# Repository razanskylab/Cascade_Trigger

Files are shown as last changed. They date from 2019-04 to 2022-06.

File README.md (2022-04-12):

# Cascade Trigger

This library was originally written to allow multiwavelength imaging in optoacoustic microscopy. After a position trigger coming from the Quadrature decoder, this library will make a burst mode trigger scheme allowing the acquisition of multiwavelength OA images within a single mechanical overfly scan. We provide a convenient MATLAB interface to define the required number of averages and number of wavelengths.

The code was tested with Teensy 3.6 and Teensy 4.1 and should be compatible with both. To programm the controller you need to download and install [Teensyduino](https://www.pjrc.com/teensy/teensyduino.html).

Depending on how you use the library, you might need to adapt a few ports.

## Literature

*  Urs A. T. Hofmann, Johannes Rebling, Héctor Estrada, Pavel Subochev, Daniel Razansky: Rapid functional optoacoustic micro-angiography in a burst mode, Optics Letters 45 (9) 2020, DOI: [10.1364/OL.387630](https://doi.org/10.1364/OL.387630)

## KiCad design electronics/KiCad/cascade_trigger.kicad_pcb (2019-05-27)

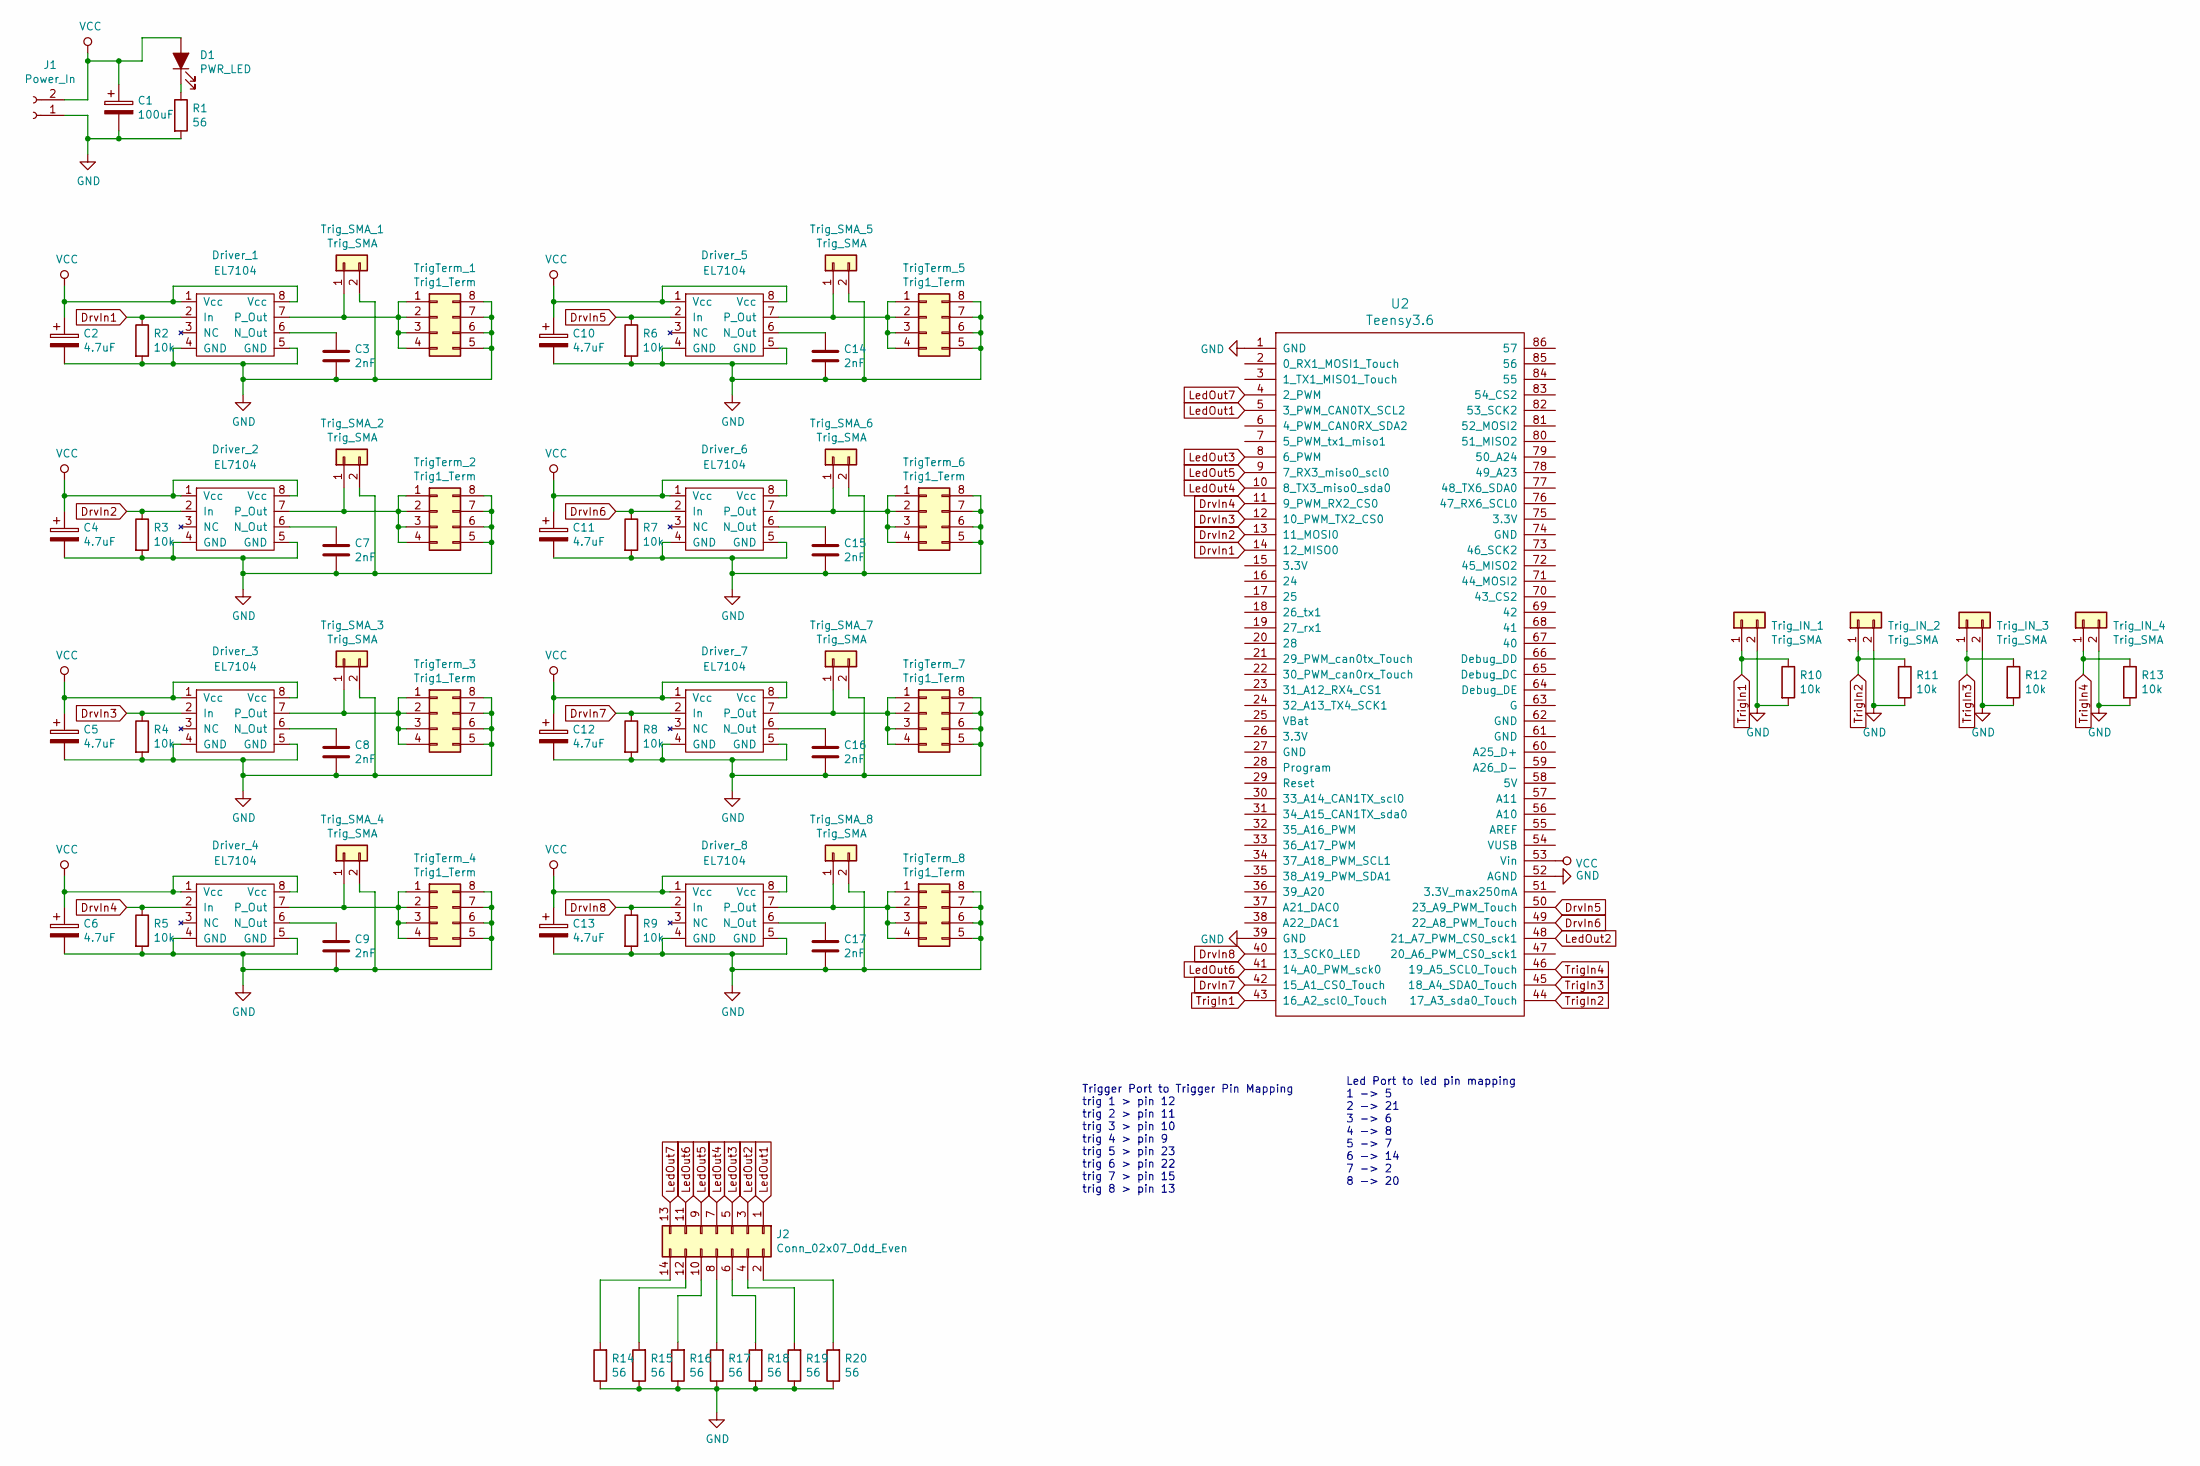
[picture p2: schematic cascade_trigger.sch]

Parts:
C1: 100uF; CP_Radial_D7.5mm_P2.50mm
C2, C4, C5, C6, C10, C11, C12, C13: 4.7uF; CP_Radial_D5.0mm_P2.00mm
C3, C7, C8, C9, C14, C15, C16, C17: 2nF; C_Disc_D3.4mm_W2.1mm_P2.50mm
D1: PWR_LED; LED_D5.0mm
Driver_1, Driver_2, Driver_3, Driver_4, Driver_5, Driver_6, Driver_7, Driver_8: EL7104; DIP-8_W7.62mm_LongPads
J1: Power_In; TerminalBlock_Altech_AK300-2_P5.00mm
J2: Conn_02x07_Odd_Even; PinHeader_2x07_P2.54mm_Vertical
R1, R14, R15, R16, R17, R18, R19, R20: 56; R_Axial_DIN0207_L6.3mm_D2.5mm_P7.62mm_Horizontal
R2, R3, R4, R5, R6, R7, R8, R9, R10, R11, R12, R13: 10k; R_Axial_DIN0207_L6.3mm_D2.5mm_P7.62mm_Horizontal
TrigTerm_1, TrigTerm_2, TrigTerm_3, TrigTerm_4, TrigTerm_5, TrigTerm_6, TrigTerm_7, TrigTerm_8: Trig1_Term; DIP-8_W7.62mm_LongPads
Trig_IN_1, Trig_IN_2, Trig_IN_3, Trig_IN_4: Trig_SMA; SMB_Jack_Vertical
Trig_SMA_1, Trig_SMA_2, Trig_SMA_3, Trig_SMA_4, Trig_SMA_5, Trig_SMA_6, Trig_SMA_7, Trig_SMA_8: Trig_SMA; SMB_Jack_Vertical
U2: Teensy3.6; Teensy35_36

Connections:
DrvIn1: Driver_1.2 (In), R2.1, U2.14 (12_MISO0)
DrvIn2: Driver_2.2 (In), R3.1, U2.13 (11_MOSI0)
DrvIn3: Driver_3.2 (In), R4.1, U2.12 (10_PWM_TX2_CS0)
DrvIn4: Driver_4.2 (In), R5.1, U2.11 (9_PWM_RX2_CS0)
DrvIn5: Driver_5.2 (In), R6.1, U2.50 (23_A9_PWM_Touch)
DrvIn6: Driver_6.2 (In), R7.1, U2.49 (22_A8_PWM_Touch)
DrvIn7: Driver_7.2 (In), R8.1, U2.42 (15_A1_CS0_Touch)
DrvIn8: Driver_8.2 (In), R9.1, U2.40 (13_SCK0_LED)
GND: C1.2, C2.2, C3.2, C4.2, C5.2, C6.2, C7.2, C8.2, C9.2, C10.2, C11.2, C12.2, C13.2, C14.2, C15.2, C16.2, C17.2, Driver_1.4 (GND), Driver_1.5 (GND), Driver_2.4 (GND), Driver_2.5 (GND), Driver_3.4 (GND), Driver_3.5 (GND), Driver_4.4 (GND), Driver_4.5 (GND), Driver_5.4 (GND), Driver_5.5 (GND), Driver_6.4 (GND), Driver_6.5 (GND), Driver_7.4 (GND), Driver_7.5 (GND), Driver_8.4 (GND), Driver_8.5 (GND), J1.1, R1.2, R2.2, R3.2, R4.2, R5.2, R6.2, R7.2, R8.2, R9.2, R10.2, R11.2, R12.2, R13.2, R14.1, R15.1, R16.1, R17.1, R18.1, R19.1, R20.1, TrigTerm_1.5, TrigTerm_1.6, TrigTerm_1.7, TrigTerm_1.8, TrigTerm_2.5, TrigTerm_2.6, TrigTerm_2.7, TrigTerm_2.8, TrigTerm_3.5, TrigTerm_3.6, TrigTerm_3.7, TrigTerm_3.8, TrigTerm_4.5, TrigTerm_4.6, TrigTerm_4.7, TrigTerm_4.8, TrigTerm_5.5, TrigTerm_5.6, TrigTerm_5.7, TrigTerm_5.8, TrigTerm_6.5, TrigTerm_6.6, TrigTerm_6.7, TrigTerm_6.8, TrigTerm_7.5, TrigTerm_7.6, TrigTerm_7.7, TrigTerm_7.8, TrigTerm_8.5, TrigTerm_8.6, TrigTerm_8.7, TrigTerm_8.8, Trig_IN_1.2, Trig_IN_2.2, Trig_IN_3.2, Trig_IN_4.2, Trig_SMA_1.2, Trig_SMA_2.2, Trig_SMA_3.2, Trig_SMA_4.2, Trig_SMA_5.2, Trig_SMA_6.2, Trig_SMA_7.2, Trig_SMA_8.2, U2.1 (GND), U2.39 (GND), U2.52 (AGND)
LedOut1: J2.1, U2.5 (3_PWM_CAN0TX_SCL2)
LedOut2: J2.3, U2.48 (21_A7_PWM_CS0_sck1)
LedOut3: J2.5, U2.8 (6_PWM)
LedOut4: J2.7, U2.10 (8_TX3_miso0_sda0)
LedOut5: J2.9, U2.9 (7_RX3_miso0_scl0)
LedOut6: J2.11, U2.41 (14_A0_PWM_sck0)
LedOut7: J2.13, U2.4 (2_PWM)
unnamed: C3.1, Driver_1.6 (N_Out)
unnamed: C7.1, Driver_2.6 (N_Out)
unnamed: C8.1, Driver_3.6 (N_Out)
unnamed: C9.1, Driver_4.6 (N_Out)
unnamed: C14.1, Driver_5.6 (N_Out)
unnamed: C15.1, Driver_6.6 (N_Out)
unnamed: C16.1, Driver_7.6 (N_Out)
unnamed: C17.1, Driver_8.6 (N_Out)
unnamed: D1.1 (K), R1.1
unnamed: Driver_1.7 (P_Out), TrigTerm_1.1, TrigTerm_1.2, TrigTerm_1.3, TrigTerm_1.4, Trig_SMA_1.1
unnamed: Driver_2.7 (P_Out), TrigTerm_2.1, TrigTerm_2.2, TrigTerm_2.3, TrigTerm_2.4, Trig_SMA_2.1
unnamed: Driver_3.7 (P_Out), TrigTerm_3.1, TrigTerm_3.2, TrigTerm_3.3, TrigTerm_3.4, Trig_SMA_3.1
unnamed: Driver_4.7 (P_Out), TrigTerm_4.1, TrigTerm_4.2, TrigTerm_4.3, TrigTerm_4.4, Trig_SMA_4.1
unnamed: Driver_5.7 (P_Out), TrigTerm_5.1, TrigTerm_5.2, TrigTerm_5.3, TrigTerm_5.4, Trig_SMA_5.1
unnamed: Driver_6.7 (P_Out), TrigTerm_6.1, TrigTerm_6.2, TrigTerm_6.3, TrigTerm_6.4, Trig_SMA_6.1
unnamed: Driver_7.7 (P_Out), TrigTerm_7.1, TrigTerm_7.2, TrigTerm_7.3, TrigTerm_7.4, Trig_SMA_7.1
unnamed: Driver_8.7 (P_Out), TrigTerm_8.1, TrigTerm_8.2, TrigTerm_8.3, TrigTerm_8.4, Trig_SMA_8.1
unnamed: J2.2, R20.2
unnamed: J2.4, R19.2
unnamed: J2.6, R18.2
unnamed: J2.8, R17.2
unnamed: J2.10, R16.2
unnamed: J2.12, R15.2
unnamed: J2.14, R14.2
TrigIn1: R10.1, Trig_IN_1.1, U2.43 (16_A2_scl0_Touch)
TrigIn2: R11.1, Trig_IN_2.1, U2.44 (17_A3_sda0_Touch)
TrigIn3: R12.1, Trig_IN_3.1, U2.45 (18_A4_SDA0_Touch)
TrigIn4: R13.1, Trig_IN_4.1, U2.46 (19_A5_SCL0_Touch)
VCC: C1.1, C2.1, C4.1, C5.1, C6.1, C10.1, C11.1, C12.1, C13.1, D1.2 (A), Driver_1.1 (Vcc), Driver_1.8 (Vcc), Driver_2.1 (Vcc), Driver_2.8 (Vcc), Driver_3.1 (Vcc), Driver_3.8 (Vcc), Driver_4.1 (Vcc), Driver_4.8 (Vcc), Driver_5.1 (Vcc), Driver_5.8 (Vcc), Driver_6.1 (Vcc), Driver_6.8 (Vcc), Driver_7.1 (Vcc), Driver_7.8 (Vcc), Driver_8.1 (Vcc), Driver_8.8 (Vcc), J1.2, U2.53 (Vin)

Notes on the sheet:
Trigger Port to Trigger Pin Mapping trig 1 > pin 12 trig 2 > pin 11 trig 3 > pin 10 trig 4 > pin 9 trig 5 > pin 23 trig 6 > pin 22 trig 7 > pin 15 trig 8 > pin 13
Led Port to led pin mapping 1 -> 5 2 -> 21 3 -> 6 4 -> 8 5 -> 7 6 -> 14 7 -> 2 8 -> 20

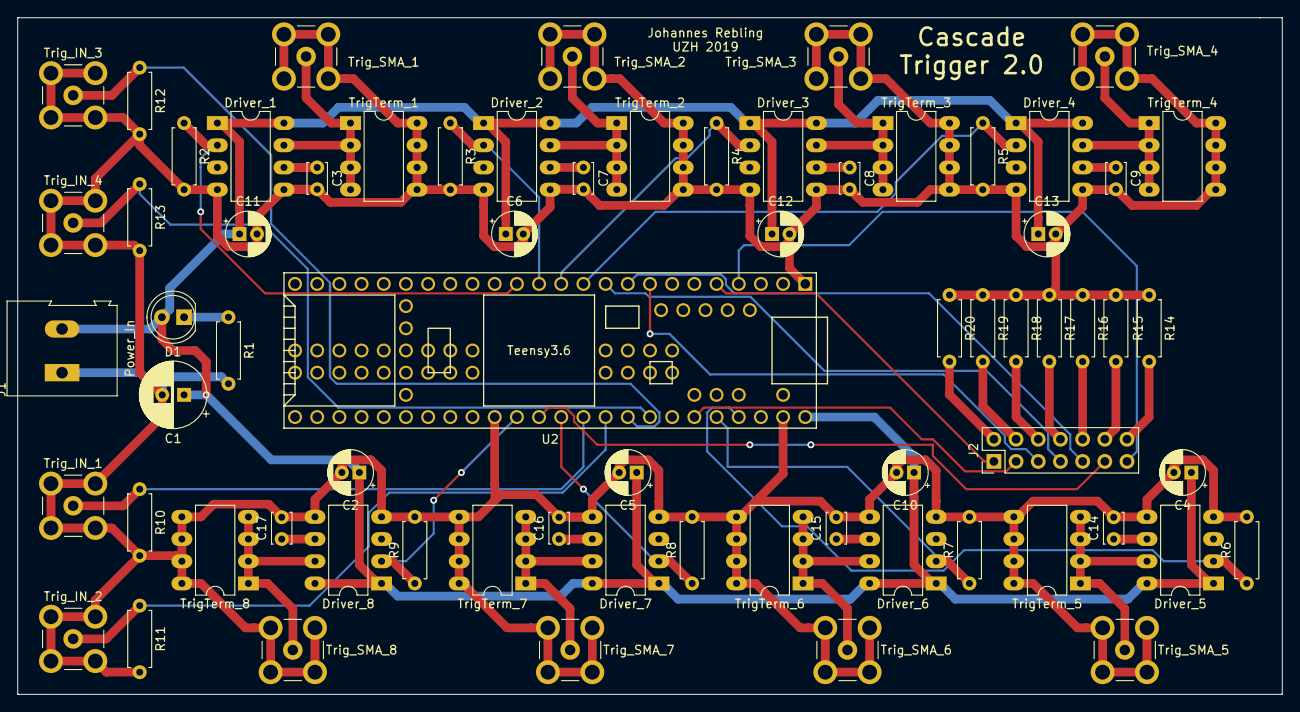
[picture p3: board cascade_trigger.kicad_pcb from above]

Board: 2 copper layers, 144.8 x 77.5 mm, 69 parts (0 on the bottom side), 45 nets.

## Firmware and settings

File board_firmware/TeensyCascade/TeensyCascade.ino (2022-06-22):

// File: TeensyCascade.ino
// Author: Urs Hofmann
// Mail: hofmannu@biomed.ee.ethz.ch
// Date: 25.04.2019
// 
// Description: Switched to minimal main file, moved stuff to class

#include "Cascader.h"

Cascader myCascader;

void setup()
{
	myCascader.setup();
}

void loop()
{
	myCascader.operate();
}

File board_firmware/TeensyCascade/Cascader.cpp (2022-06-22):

#include "Cascader.h"


// just an empty constructor for now
Cascader::Cascader()
{

}

// device setup function
void Cascader::setup()
{
	Serial.begin(115200); // start serial communication
	pinMode(LED_STATUS, OUTPUT); // make led output
	pinMode(INPUT_PINS[inputPin], INPUT_PULLUP); // declare input line
}

// wait until a certain amount of serial bytes arrived
void Cascader::wait_for_serial(const uint16_t nSerial)
{
	while (Serial.available() < nSerial)
	{
		delayMicroseconds(1);
	}
	return;
}

// ifentifies the board with a LED blink
void Cascader::identify()
{
	SerialNumbers::send_uint16(IDENTIFIER);
	digitalWrite(LED_STATUS, HIGH);
	delay(250);
	digitalWrite(LED_STATUS, LOW);
	return;
}

void Cascader::operate()
{
	wait_for_serial(1);

	uint8_t mode = SerialNumbers::read_uint8(); // read serial byte
	if (mode == IDENTIFY) // identify device for COM port detection
	{
		identify();
		SerialNumbers::send_uint8(OK);
	}
	// define number of averages acquired at each trigger event
	else if (mode == SET_AVERAGES)
	{
		nAverages = SerialNumbers::read_uint32();
		SerialNumbers::send_uint32(nAverages);
		SerialNumbers::send_uint8(OK);
	}
	// return number of averages currently defined on microcontroller
	else if (mode == GET_AVERAGES)
	{
		SerialNumbers::send_uint32(nAverages);
		SerialNumbers::send_uint8(OK);
	}
	// define total number of shots we want to fire
	else if (mode == SET_NSHOTS)
	{
		nShots = SerialNumbers::read_uint32();
		SerialNumbers::send_uint32(nShots);
		SerialNumbers::send_uint8(OK);
	}
	else if (mode == GET_NSHOTS)
	{
		SerialNumbers::send_uint32(nShots);
		SerialNumbers::send_uint8(OK);
	}
	else if (mode == SET_TACQUIRE)
	{
		tAcquire = SerialNumbers::read_float();
		SerialNumbers::send_float(tAcquire);
		SerialNumbers::send_uint8(OK);
	}
	else if (mode == GET_TACQUIRE)
	{
		SerialNumbers::send_float(tAcquire);
		SerialNumbers::send_uint8(OK);
	}
	else if (mode == GET_TON)
	{	
		const uint8_t idLaser = SerialNumbers::read_uint8();
		SerialNumbers::send_uint8(idLaser);
		SerialNumbers::send_float(chArray[idLaser].get_onTime());
		SerialNumbers::send_uint8(OK);
	}
	else if (mode == SET_TON)
	{
		// receive ID and trigger timepoint
		const uint8_t idLaser = SerialNumbers::read_uint8();
		const float tTrig = SerialNumbers::read_float();

		chArray[idLaser].set_onTime(tTrig);

		// send back confirmation
		SerialNumbers::send_uint8(idLaser);
		SerialNumbers::send_float(chArray[idLaser].get_onTime());
		SerialNumbers::send_uint8(OK);
	}
	else if (mode == GET_TOFF)
	{	
		const uint8_t idLaser = SerialNumbers::read_uint8();
		SerialNumbers::send_uint8(idLaser);
		SerialNumbers::send_float(chArray[idLaser].get_offTime());
		SerialNumbers::send_uint8(OK);
	}
	else if (mode == SET_TOFF)
	{
		// receive ID and trigger timepoint
		const uint8_t idLaser = SerialNumbers::read_uint8();
		const float tTrig = SerialNumbers::read_float();

		chArray[idLaser].set_offTime(tTrig);

		// send back confirmation
		SerialNumbers::send_uint8(idLaser);
		SerialNumbers::send_float(chArray[idLaser].get_offTime());
		SerialNumbers::send_uint8(OK);
	}
	else if (mode == SET_TDAC)
	{
		for (uint8_t iChannel = 0; iChannel < nChannels; iChannel++)
		{
			const float tempVal = SerialNumbers::read_float();
			chDac.set_trigTime(tempVal , iChannel);
			SerialNumbers::send_float(chDac.get_trigTime(iChannel));
		}
		SerialNumbers::send_uint8(OK);
	}
	else if (mode == GET_TDAC)
	{
		const uint8_t iChannel = SerialNumbers::read_uint8();
		SerialNumbers::send_float(chDac.get_trigTime(iChannel));
		SerialNumbers::send_uint8(OK);  
	}
	else if (mode == SET_INPUT_PIN)
	{
		const uint8_t iChannel = SerialNumbers::read_uint8();
		define_input_pin(iChannel - 1);
		SerialNumbers::send_uint8(inputPin + 1);
		SerialNumbers::send_uint8(OK);
	}
	else if (mode == GET_INPUT_PIN)
	{
		SerialNumbers::send_uint8(inputPin + 1);
		SerialNumbers::send_uint8(OK);
	}
	else if (mode == START_CASCADE)
	{
		SerialNumbers::send_uint8(OK);
		// here we now distinguish between the two modes
		if (nShots > 0)
		{
			start_ncascade();
		}
		else
		{
			start_scascade();
		}
	}
	else if (mode == STOP_CASCADE)
	{
		SerialNumbers::send_uint16(0);
		SerialNumbers::send_uint8(WARNING);
	}
	else if (mode == SET_TRIGTYPE)
	{
		inputTrigType = SerialNumbers::read_uint8();
		SerialNumbers::send_uint8(inputTrigType);
		SerialNumbers::send_uint8(OK);
	}
	else if (mode == GET_TRIGTYPE)
	{
		SerialNumbers::send_uint8(inputTrigType);
		SerialNumbers::send_uint8(OK);
	}
	else // this means invalid command
	{
		SerialNumbers::send_uint8(ERROR);
	}
	return;
}

void Cascader::define_input_pin(const uint8_t iChannel)
{
	pinMode(INPUT_PINS[iChannel], INPUT_PULLUP);
	inputPin = iChannel;
	return;
}

void Cascader::check_trigger()
{
	if (inputTrigType == TRIG_BOTH)
	{
		if(oldStatus ^ digitalReadFast(INPUT_PINS[inputPin])){	
			oldStatus = !oldStatus; // invert oldStatus
			cascade(); // start event loop
		 	iTrigger++;
		}
	}
	else if (inputTrigType == TRIG_RISING)
	{
		if(digitalReadFast(INPUT_PINS[inputPin])){	
			cascade(); // start event loop
		 	iTrigger++;

		 	while(digitalReadFast(INPUT_PINS[inputPin]))
			{
				// do nothing
			}
		}
	}
	else // if we are here it must be falling edge
	{
		if(!digitalReadFast(INPUT_PINS[inputPin])){	
			cascade(); // start event loop
		 	iTrigger++;

		 	while(!digitalReadFast(INPUT_PINS[inputPin]))
			{
				// do nothing
			}
		}		
	}
	return;
}

// starts the cascade until we are done with the specified number of iterationsd
void Cascader::start_ncascade()
{
	iTrigger = 0;
	digitalWriteFast(LED_STATUS, HIGH);
	oldStatus = digitalReadFast(INPUT_PINS[inputPin]);

	do{
		check_trigger();
	}while (iTrigger < nShots);

	digitalWriteFast(LED_STATUS, LOW);

	// here we do not send back the number of trigger events since they are predefined 
	SerialNumbers::send_uint8(OK);

	return;
}

// in this case we run the cascade until we receive a serial interupt
void Cascader::start_scascade()
{
	digitalWriteFast(LED_STATUS, HIGH);
	bool oldStatus = digitalReadFast(INPUT_PINS[inputPin]);
	uint16_t iTrigger = 0;
	do{ // trigger because of signal from position board
		if(oldStatus ^ digitalReadFast(INPUT_PINS[inputPin])){	
			oldStatus = !oldStatus; // invert oldStatus
			cascade(); // start event loop
		 	iTrigger++;
		}
	}while(Serial.available() == 0);

	const uint8_t tempResponse = SerialNumbers::read_uint8();
	if (tempResponse == STOP_CASCADE)
	{
		SerialNumbers::send_uint16(iTrigger);
		SerialNumbers::send_uint8(OK);
	}
	else
	{
		SerialNumbers::send_uint8(ERROR);
	}

	// once we are done with read the stop bit
	digitalWriteFast(LED_STATUS, LOW);
}
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

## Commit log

2019-04-27 pcb and firmware basics
    [cascade_trigger_01.fzz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]
2019-05-27 board PCB and simple trigger code
    [cascade_trigger-B_Cu.gbl, cascade_trigger-B_Mask.gbs, cascade_trigger-B_SilkS.gbo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]
2019-05-27 'quick' fix for OR microscope
    [cascade_trigger.kicad_pcb]
2019-05-27 not sure what I did here...
    [cascade_trigger_02.fzz]
2019-06-24 stand alone trigger board
2019-06-24 fixing bugs, making it work...
    [main.cpp]
2019-09-29 clean up of old schematics and code
    [cascade_trigger-B_Cu.gbl, cascade_trigger-B_Mask.gbs, cascade_trigger-B_SilkS.gbo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]
2019-10-07 camera triggering working OK
2019-10-12 trigger board fine-tuning
2021-12-17 fixed serial delay issue
    [TeensyCascade.ino]
